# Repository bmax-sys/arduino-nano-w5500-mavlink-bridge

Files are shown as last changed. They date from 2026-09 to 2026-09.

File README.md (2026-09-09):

<p align="center">
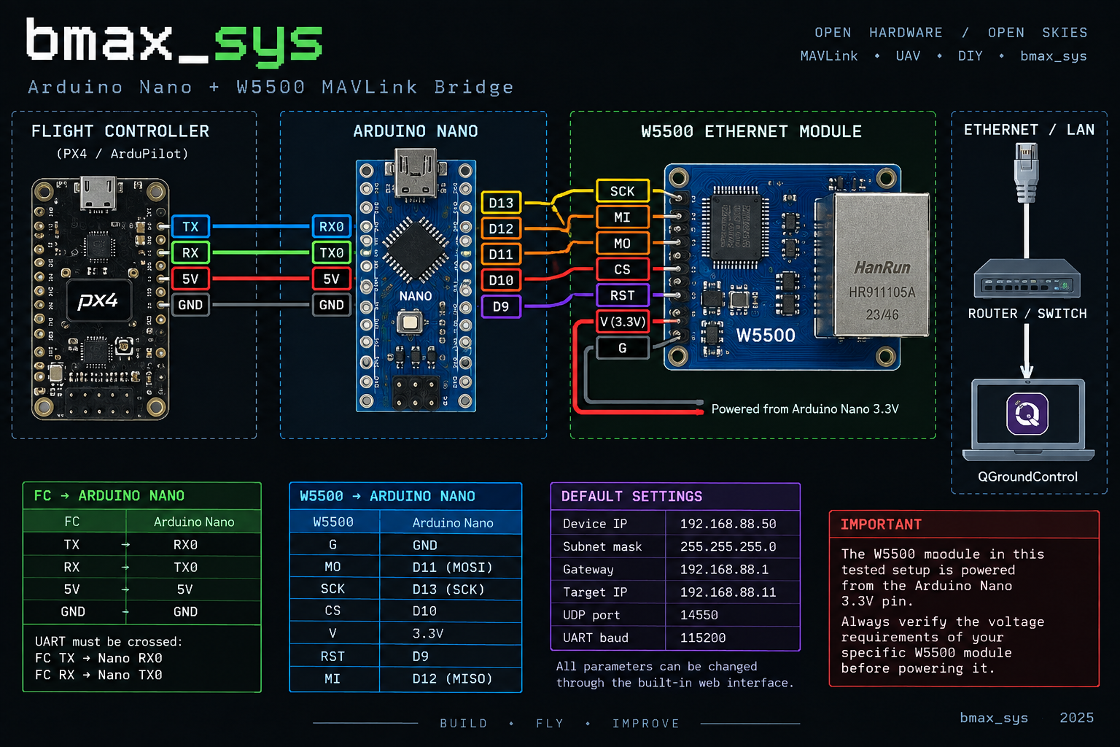
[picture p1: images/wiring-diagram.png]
bmax_sys Arduino Nano + W5500 MAVLink Bridge wiring diagram
  
</p>

# Arduino Nano + W5500 MAVLink Bridge

**UART ↔ Ethernet bridge for MAVLink telemetry based on Arduino Nano and W5500.**

Built by `bmax_sys`.

## Overview

This project turns an Arduino Nano and W5500 Ethernet module into a bidirectional UART-to-Ethernet bridge for MAVLink communication.

The flight controller sends MAVLink data through UART to the Arduino Nano. The Nano forwards the data through the W5500 Ethernet module using UDP.

Communication works in both directions:

`Flight Controller ↔ UART ↔ Arduino Nano ↔ W5500 ↔ Ethernet/UDP ↔ QGroundControl`

The device also includes a built-in web interface for changing network and UART settings without modifying or recompiling the firmware.

## Features

- Bidirectional `UART ↔ UDP` MAVLink bridge
- Arduino Nano + W5500 Ethernet
- Built-in web configuration interface
- Configurable Device IP
- Configurable Target IP
- Configurable Subnet Mask
- Configurable Gateway
- Configurable UDP port
- Configurable UART baud rate
- Settings stored in EEPROM
- Save & automatic reboot from the web interface
- Default MAVLink UDP port `14550`
- Works with QGroundControl
- Designed for wired Ethernet telemetry

  ## Hardware

The tested prototype uses:

- Arduino Nano
- W5500 Ethernet module
- ArduPilot-compatible flight controller
- Ethernet cable
- UART connection between the flight controller and Arduino Nano

  ## 3D Printable Enclosure

A 3D printable enclosure for the Arduino Nano + W5500 MAVLink Bridge is included in this repository.

STL file:

[`enclosure/ETH-NANO.STL`](enclosure/ETH-NANO.STL)

The enclosure is designed for the hardware configuration used in this project and can be printed on a standard FDM 3D printer.

Before printing, verify the dimensions and connector positions for your specific Arduino Nano and W5500 modules.

### Connections

**Flight Controller → Arduino Nano**

`TX → RX0`  
`RX → TX0`  
`5V → 5V`  
`GND → GND`

**W5500 → Arduino Nano**

`MO → D11`  
`MI → D12`  
`SCK → D13`  
`CS → D10`  
`RST → D9`  
`V → 3.3V`  
`G → GND`

For the complete wiring description, see:

[`docs/WIRING.md`](docs/WIRING.md)

## Default Configuration

The firmware starts with the following default settings:

| Parameter | Default value |
|---|---|
| Device IP | `192.168.88.50` |
| Subnet Mask | `255.255.255.0` |
| Gateway | `192.168.88.1` |
| Target IP | `192.168.88.11` |
| UDP Port | `14550` |
| UART Baud Rate | `115200` |

The settings can be changed through the built-in web interface and are stored in EEPROM.

After changing the configuration, press **SAVE & REBOOT** to store the new settings and restart the device.

## Web Interface

<p align="center">
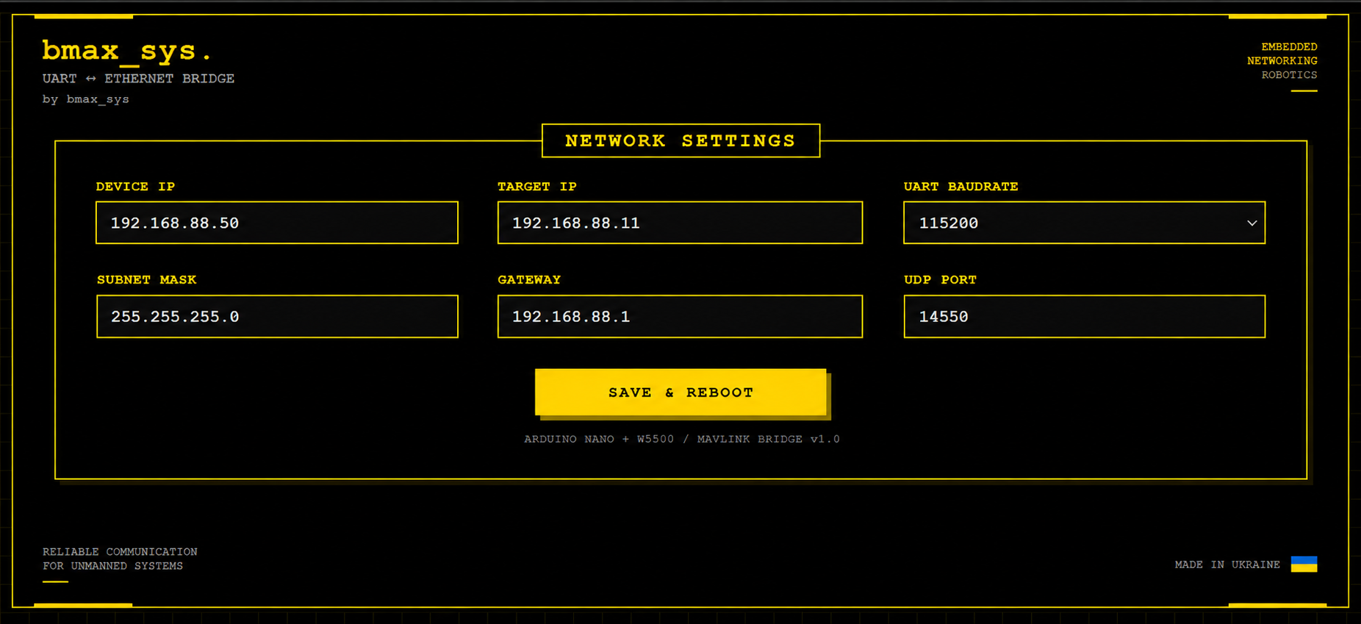
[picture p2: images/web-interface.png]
bmax_sys Arduino Nano W5500 MAVLink Bridge Web Interface
  
</p>

The bridge includes a lightweight built-in web interface hosted directly by the Arduino Nano.

Open the device IP address in a web browser:

`http://192.168.88.50`

The interface allows you to configure:

- Device IP
- Target IP
- UART baud rate
- Subnet mask
- Gateway
- UDP port

After pressing **SAVE & REBOOT**, the configuration is stored in EEPROM and the Arduino Nano automatically restarts with the new settings.

The public version of the interface uses the `bmax_sys` pixel-style branding.

## MAVLink and QGroundControl

The bridge was designed for MAVLink telemetry between an ArduPilot flight controller and QGroundControl.

Default data path:

`Flight Controller → UART → Arduino Nano → W5500 → UDP 14550 → QGroundControl`

Communication is bidirectional:

`QGroundControl → UDP → W5500 → Arduino Nano → UART → Flight Controller`

By default, MAVLink packets are sent to:

`192.168.88.11:14550`

The Target IP and UDP port can be changed from the web interface, allowing the bridge to work with different network configurations.

## Firmware

The firmware is available here:

[`firmware/arduino_nano_w5500_mavlink_bridge.ino`](firmware/arduino_nano_w5500_mavlink_bridge.ino)

Main firmware functions:

- UART → UDP forwarding
- UDP → UART forwarding
- W5500 Ethernet initialization
- Web configuration server
- EEPROM configuration storage
- IP address validation
- Configurable UART baud rate
- Automatic reboot after saving settings

The firmware is based on the Arduino Ethernet library and is designed to keep memory usage low enough for the Arduino Nano.

## Repository Structure

```text
arduino-nano-w5500-mavlink-bridge/
├── README.md
├── firmware/
│   └── arduino_nano_w5500_mavlink_bridge.ino
├── docs/
│   ├── WIRING.md
│   └── TESTING.md
├── images/
│   ├── wiring-diagram.png
│   └── web-interface.png
└── enclosure/
    └── ETH-NANO.STL
```

## Tested

The prototype has been tested with real hardware.

Confirmed:

- Arduino Nano communicates with the W5500 over SPI
- Flight controller communicates with the Nano over UART
- MAVLink telemetry is transmitted over Ethernet
- UDP communication works in both directions
- QGroundControl receives MAVLink telemetry
- Web configuration interface works
- Network settings can be changed and stored in EEPROM
- Device automatically reboots after saving settings

This repository documents a working hardware prototype, not only a theoretical design.
For detailed test results and verification steps, see:

[`docs/TESTING.md`](docs/TESTING.md)

## Important Notes

- Always connect UART lines crossed: `FC TX → Nano RX0` and `FC RX → Nano TX0`.
- Flight controller and Arduino Nano must share a common GND.
- The tested W5500 module is powered from the Arduino Nano `3.3V` pin.
- Verify the power requirements of your specific W5500 module before connecting it.
- Make sure the configured Target IP points to the computer running QGroundControl.
- UDP port `14550` is the default MAVLink port used in this project.

  ## Author

Developed and tested by `bmax_sys`.

Part of a series of embedded, networking and robotics projects focused on reliable communication for unmanned systems.

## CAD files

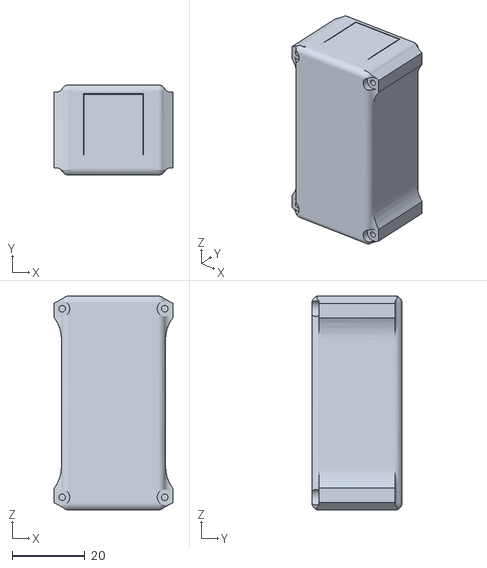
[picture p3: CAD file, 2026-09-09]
enclosure/ETH-NANO.STL
32.7 x 24.9 x 59.0

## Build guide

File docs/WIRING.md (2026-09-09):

# Wiring

This project uses an Arduino Nano and a W5500 Ethernet module as a bidirectional UART-to-Ethernet bridge for MAVLink telemetry.

## W5500 to Arduino Nano

| W5500 | Arduino Nano |
|---|---|
| G | GND |
| MO | D11 |
| SCK | D13 |
| CS | D10 |
| V | 3.3V |
| RST | D9 |
| MI | D12 |

SPI mapping:

- `D11` — MOSI
- `D12` — MISO
- `D13` — SCK
- `D10` — CS
- `D9` — W5500 Reset

## Arduino Nano to Flight Controller

| Arduino Nano | Flight Controller |
|---|---|
| RX0 | TX |
| TX0 | RX |
| 5V | 5V |
| GND | GND |

UART must be crossed:

`FC TX → Nano RX0`

`FC RX → Nano TX0`

## Data path

`Flight Controller → UART → Arduino Nano → W5500 → Ethernet → UDP → QGroundControl`

The bridge is bidirectional, so MAVLink data can travel in both directions between the flight controller and the network.

## Default network settings

- Device IP: `192.168.88.50`
- Subnet mask: `255.255.255.0`
- Gateway: `192.168.88.1`
- Target IP: `192.168.88.11`
- UDP port: `14550`
- UART baud rate: `115200`

These parameters can be changed through the built-in web interface.

## Important

The W5500 module in this tested setup is powered from the Arduino Nano `3.3V` pin.

Always verify the voltage requirements of your specific W5500 module before powering it.

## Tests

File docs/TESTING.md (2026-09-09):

# Testing

The Arduino Nano + W5500 MAVLink Bridge was tested with real hardware.

## Test Hardware

- Arduino Nano
- W5500 Ethernet module
- ArduPilot-compatible flight controller
- Ethernet network
- QGroundControl

## Test Configuration

Default bridge configuration:

| Parameter | Value |
|---|---|
| Device IP | `192.168.88.50` |
| Subnet Mask | `255.255.255.0` |
| Gateway | `192.168.88.1` |
| Target IP | `192.168.88.11` |
| UDP Port | `14550` |
| UART Baud Rate | `115200` |

## Data Path

The complete tested communication path:

`Flight Controller ↔ UART ↔ Arduino Nano ↔ SPI ↔ W5500 ↔ Ethernet/UDP ↔ QGroundControl`

## UART Test

The flight controller was connected directly to the Arduino Nano UART:

`FC TX → Nano RX0`

`FC RX → Nano TX0`

A common ground was used between the flight controller and Arduino Nano.

MAVLink data was successfully transferred through the UART connection.

## Ethernet Test

The Arduino Nano communicates with the W5500 Ethernet controller over SPI.

The W5500 successfully provides Ethernet connectivity for the bridge using the configured static IP address.

## MAVLink / UDP Test

MAVLink telemetry was forwarded from UART to Ethernet using UDP.

Default destination:

`192.168.88.11:14550`

QGroundControl successfully received MAVLink telemetry from the flight controller.

Communication was also verified in the opposite direction:

`QGroundControl → UDP → W5500 → Arduino Nano → UART → Flight Controller`

This confirms bidirectional UART ↔ UDP communication.

## Web Interface Test

The built-in configuration interface was accessed through:

`http://192.168.88.50`

The following parameters can be changed from the web interface:

- Device IP
- Target IP
- Subnet Mask
- Gateway
- UDP Port
- UART Baud Rate

The configuration is stored in EEPROM.

After pressing **SAVE & REBOOT**, the device saves the new settings and automatically restarts.

## Result

The prototype successfully provides a bidirectional MAVLink bridge between a flight controller UART and an Ethernet network.

Confirmed:

- Arduino Nano ↔ W5500 SPI communication
- Flight Controller ↔ Arduino Nano UART communication
- UART → UDP forwarding
- UDP → UART forwarding
- QGroundControl MAVLink telemetry
- Bidirectional MAVLink communication
- Built-in web configuration
- EEPROM configuration storage
- Automatic reboot after configuration changes

The project has been verified as a working hardware prototype.

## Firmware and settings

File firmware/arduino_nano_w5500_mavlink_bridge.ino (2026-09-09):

#include <SPI.h>
#include <Ethernet.h>
#include <EthernetUdp.h>
#include <EEPROM.h>
#include <avr/wdt.h>

// =====================================================
// bmax_sys
// Arduino Nano + W5500 MAVLink Bridge
// Arduino Nano + W5500
// UART <-> UDP + EEPROM + WEB SETTINGS
// =====================================================

#define W5500_CS  10
#define W5500_RST 9

byte mac[] = {0x02, 0x4D, 0x41, 0x58, 0x58, 0x06};

const byte DEF_DEVICE_IP[4] = {192,168,88,50};
const byte DEF_MASK[4]      = {255,255,255,0};
const byte DEF_GATEWAY[4]   = {192,168,88,1};
const byte DEF_TARGET_IP[4] = {192,168,88,11};

const uint16_t DEF_UDP_PORT = 14550;
const uint32_t DEF_BAUD     = 115200;

const uint32_t SETTINGS_MAGIC = 0x424D5831UL; // "BMX1"

struct Settings {
  uint32_t magic;
  byte deviceIP[4];
  byte mask[4];
  byte gateway[4];
  byte targetIP[4];
  uint16_t udpPort;
  uint32_t baud;
};

Settings cfg;

IPAddress deviceIP;
IPAddress subnetMask;
IPAddress gatewayIP;
IPAddress targetIP;

uint16_t udpPort = DEF_UDP_PORT;
uint32_t uartBaud = DEF_BAUD;

EthernetUDP udp;
EthernetServer server(80);

// Small buffers to protect Nano SRAM
byte uartBuffer[64];
byte udpBuffer[64];
byte uartLen = 0;
unsigned long lastByteTime = 0;

// =====================================================
// SETTINGS
// =====================================================

void copy4(byte *dst, const byte *src) {
  for (byte i = 0; i < 4; i++) dst[i] = src[i];
}

void setDefaults() {
  cfg.magic = SETTINGS_MAGIC;

  copy4(cfg.deviceIP, DEF_DEVICE_IP);
  copy4(cfg.mask, DEF_MASK);
  copy4(cfg.gateway, DEF_GATEWAY);
  copy4(cfg.targetIP, DEF_TARGET_IP);

  cfg.udpPort = DEF_UDP_PORT;
  cfg.baud = DEF_BAUD;
}

void applySettings() {
  deviceIP = IPAddress(
    cfg.deviceIP[0], cfg.deviceIP[1],
    cfg.deviceIP[2], cfg.deviceIP[3]
  );

  subnetMask = IPAddress(
    cfg.mask[0], cfg.mask[1],
    cfg.mask[2], cfg.mask[3]
  );

  gatewayIP = IPAddress(
    cfg.gateway[0], cfg.gateway[1],
    cfg.gateway[2], cfg.gateway[3]
  );

  targetIP = IPAddress(
    cfg.targetIP[0], cfg.targetIP[1],
    cfg.targetIP[2], cfg.targetIP[3]
  );

  udpPort = cfg.udpPort;
  uartBaud = cfg.baud;
}

void loadSettings() {
  EEPROM.get(0, cfg);

  if (cfg.magic != SETTINGS_MAGIC) {
    setDefaults();
    EEPROM.put(0, cfg);
  }

  applySettings();
}

void saveSettings() {
  cfg.magic = SETTINGS_MAGIC;
  EEPROM.put(0, cfg);
}

// =====================================================
// HELPERS
// =====================================================

bool parseIP(const char *s, byte out[4]) {
  int a, b, c, d;

  if (sscanf(s, "%d.%d.%d.%d", &a, &b, &c, &d) != 4) {
    return false;
  }

  if (a < 0 || a > 255 ||
      b < 0 || b > 255 ||
      c < 0 || c > 255 ||
      d < 0 || d > 255) {
    return false;
  }

  out[0] = (byte)a;
  out[1] = (byte)b;
  out[2] = (byte)c;
  out[3] = (byte)d;

  return true;
}

void printIP(EthernetClient &client, const byte ip[4]) {
  client.print(ip[0]); client.print('.');
  client.print(ip[1]); client.print('.');
  client.print(ip[2]); client.print('.');
  client.print(ip[3]);
}

bool getQueryValue(const char *request,
                   const char *key,
                   char *out,
                   byte outSize) {
  char token[18];
  snprintf(token, sizeof(token), "%s=", key);

  const char *p = strstr(request, token);
  if (!p) return false;

  p += strlen(token);

  byte i = 0;

  while (*p &&
         *p != '&' &&
         *p != ' ' &&
         i < outSize - 1) {
    out[i++] = *p++;
  }

  out[i] = 0;
  return true;
}

void rebootNano() {
  wdt_enable(WDTO_15MS);
  while (1) {}
}

// =====================================================
// UART -> UDP
// =====================================================

void uartToUDP() {
  while (Serial.available() && uartLen < sizeof(uartBuffer)) {
    uartBuffer[uartLen++] = Serial.read();
    lastByteTime = micros();
  }

  if (uartLen > 0 &&
      ((micros() - lastByteTime) > 2000 ||
       uartLen >= sizeof(uartBuffer))) {

    udp.beginPacket(targetIP, udpPort);
    udp.write(uartBuffer, uartLen);
    udp.endPacket();

    uartLen = 0;
  }
}

// =====================================================
// UDP -> UART
// =====================================================

void udpToUART() {
  int packetSize = udp.parsePacket();

  if (packetSize <= 0) return;

  while (packetSize > 0) {
    int chunk = packetSize;

    if (chunk > (int)sizeof(udpBuffer)) {
      chunk = sizeof(udpBuffer);
    }

    int len = udp.read(udpBuffer, chunk);

    if (len <= 0) break;

    Serial.write(udpBuffer, len);
    packetSize -= len;
  }
}

// =====================================================
// WEB
// =====================================================

void sendHttpHeader(EthernetClient &client) {
  client.println(F("HTTP/1.1 200 OK"));
  client.println(F("Content-Type: text/html; charset=UTF-8"));
  client.println(F("Cache-Control: no-store"));
  client.println(F("Connection: close"));
  client.println();
}

void sendSettingsPage(EthernetClient &client) {
  sendHttpHeader(client);

  client.println(F("<!DOCTYPE html><html><head>"));
  client.println(F("<meta charset='UTF-8'><meta name='viewport' content='width=device-width,initial-scale=1'>"));
  client.println(F("<title>bmax_sys | Nano W5500 MAVLink Bridge</title>"));

  client.println(F(
    "<style>"
    ":root{--y:#ffcc00;--g:rgba(255,204,0,.10);--f:#d0d0d0}"
    "*{box-sizing:border-box}"
    "html,body{margin:0;padding:0;width:100%;min-height:100%;background:#000;color:var(--y);font-family:'Courier New',Consolas,monospace}"
    "body{min-height:100vh;background-image:linear-gradient(var(--g) 1px,transparent 1px),linear-gradient(90deg,var(--g) 1px,transparent 1px);background-size:32px 32px}"
    ".frame{min-height:calc(100vh - 24px);margin:12px;border:2px solid var(--y);position:relative;background:#000;overflow:hidden}"
    ".frame:before,.frame:after{content:'';position:absolute;width:110px;height:6px;background:var(--y);top:-2px}"
    ".frame:before{left:24px}.frame:after{right:24px}"
    ".brand{position:absolute;top:22px;left:32px;z-index:10}.brand-main{font-family:'Lucida Console','Courier New',monospace;font-size:28px;font-weight:900;letter-spacing:3px;text-shadow:2px 0 0 #665200}"
    ".brand-sub{margin-top:4px;font-size:12px;letter-spacing:1px;color:#aaa}"
    ".top-right{position:absolute;top:26px;right:34px;font-weight:900;letter-spacing:3px;font-size:18px}"
  ));

  client.println(F(
    ".settings-wrapper{width:100%;padding:125px 50px 45px}"
    ".settings-panel{position:relative;width:100%;border:2px solid var(--y);padding:42px 42px 38px;background:#000;box-shadow:6px 6px 0 rgba(255,204,0,.08)}"
    ".panel-title{position:absolute;top:-20px;left:50%;transform:translateX(-50%);padding:5px 24px;background:#000;border:2px solid var(--y);font-weight:900;font-size:22px;letter-spacing:3px;white-space:nowrap}"
    ".settings-grid{display:grid;grid-template-columns:1fr 1fr 1fr;gap:26px 42px}"
    ".field label{display:block;margin-bottom:9px;font-size:15px;font-weight:900;letter-spacing:1px}"
    "input,select{width:100%;height:48px;padding:0 14px;color:var(--f);background:#050505;border:2px solid var(--y);outline:none;border-radius:0;font-family:'Courier New',Consolas,monospace;font-size:18px;font-weight:700}"
    ".button-wrapper{display:flex;justify-content:center;margin-top:34px}"
    ".save-button{min-width:320px;height:52px;border:2px solid var(--y);background:var(--y);color:#000;font-family:'Courier New',Consolas,monospace;font-size:17px;font-weight:900;letter-spacing:2px;cursor:pointer;box-shadow:5px 5px 0 #8f7300}"
    ".foot{text-align:center;margin-top:18px;color:#777;font-size:11px;letter-spacing:1px}"
    "@media(max-width:900px){.settings-grid{grid-template-columns:1fr}.settings-wrapper{padding:135px 20px 30px}.panel-title{font-size:17px}.save-button{min-width:100%}}"
    "</style></head><body><div class='frame'>"
  ));

  client.println(F("<div class='brand'><div class='brand-main'>bmax_sys</div><div class='brand-sub'>UART / ETHERNET MAVLink BRIDGE</div></div>"));
  client.println(F("<div class='top-right'>bmax_sys</div>"));
  client.println(F("<div class='settings-wrapper'><form method='GET' action='/save'><div class='settings-panel'>"));
  client.println(F("<div class='panel-title'>NETWORK SETTINGS</div><div class='settings-grid'>"));

  client.print(F("<div class='field'><label>DEVICE IP</label><input name='deviceIP' value='"));
  printIP(client, cfg.deviceIP);
  client.println(F("' required></div>"));

  client.print(F("<div class='field'><label>TARGET IP</label><input name='targetIP' value='"));
  printIP(client, cfg.targetIP);
  client.println(F("' required></div>"));

  client.println(F("<div class='field'><label>UART BAUDRATE</label><select name='baud'>"));
  const uint32_t rates[] = {9600UL,19200UL,38400UL,57600UL,115200UL,230400UL};
  for (byte i=0;i<6;i++) {
    client.print(F("<option value='")); client.print(rates[i]); client.print('\'');
    if (cfg.baud == rates[i]) client.print(F(" selected"));
    client.print('>'); client.print(rates[i]); client.println(F("</option>"));
  }
  client.println(F("</select></div>"));

  client.print(F("<div class='field'><label>SUBNET MASK</label><input name='mask' value='"));
  printIP(client, cfg.mask);
  client.println(F("' required></div>"));

  client.print(F("<div class='field'><label>GATEWAY</label><input name='gateway' value='"));
  printIP(client, cfg.gateway);
  client.println(F("' required></div>"));

  client.print(F("<div class='field'><label>UDP PORT</label><input type='number' name='port' value='"));
  client.print(cfg.udpPort);
  client.println(F("' required></div>"));

  client.println(F(
    "</div><div class='button-wrapper'><button type='submit' class='save-button'>SAVE & REBOOT</button></div>"
    "<div class='foot'>ARDUINO NANO + W5500 / bmax_sys v1.0</div>"
    "</div></form></div></div></body></html>"
  ));
}
void sendSavedPage(EthernetClient &client) {
  sendHttpHeader(client);
  client.println(F(
    "<!DOCTYPE html><html><head><meta charset='UTF-8'><meta name='viewport' content='width=device-width,initial-scale=1'>"
    "<title>Settings Saved</title><style>"
    "body{margin:0;background:#000;color:#ffcc00;font-family:'Courier New',Consolas,monospace}"
    ".frame{min-height:calc(100vh - 24px);margin:12px;border:2px solid #ffcc00;display:flex;align-items:center;justify-content:center;text-align:center}"
    ".box{padding:34px;border:2px solid #ffcc00;box-shadow:6px 6px 0 rgba(255,204,0,.10)}"
    ".check{width:70px;height:70px;margin:0 auto 22px;border:3px solid #ffcc00;display:flex;align-items:center;justify-content:center;font-size:38px;font-weight:900}"
    "h1{margin:0 0 10px;font-size:28px;letter-spacing:2px}.line{height:2px;background:#ffcc00;margin:24px 0}.ip{font-size:18px;font-weight:900}"
    "</style></head><body><div class='frame'><div class='box'>"
    "<div class='check'>&#10003;</div><h1>SETTINGS SAVED</h1><div>Device is rebooting...</div>"
    "<div class='line'></div><div>Reconnect to:</div><div class='ip'>http://"
  ));
  printIP(client, cfg.deviceIP);
  client.println(F("</div></div></div></body></html>"));
}
void sendError(EthernetClient &client, const __FlashStringHelper *msg) {
  client.println(F("HTTP/1.1 400 Bad Request"));
  client.println(F("Content-Type: text/plain"));
  client.println(F("Connection: close"));
  client.println();
  client.println(msg);
}

void handleSave(EthernetClient &client, const char *request) {
  char value[24];
  byte tempIP[4];

  if (!getQueryValue(request, "deviceIP", value, sizeof(value)) ||
      !parseIP(value, tempIP)) {
    sendError(client, F("Invalid Device IP"));
    return;
  }
  copy4(cfg.deviceIP, tempIP);

  if (!getQueryValue(request, "targetIP", value, sizeof(value)) ||
      !parseIP(value, tempIP)) {
    sendError(client, F("Invalid Target IP"));
    return;
  }
  copy4(cfg.targetIP, tempIP);

  if (!getQueryValue(request, "mask", value, sizeof(value)) ||
      !parseIP(value, tempIP)) {
    sendError(client, F("Invalid Subnet Mask"));
    return;
  }
  copy4(cfg.mask, tempIP);

  if (!getQueryValue(request, "gateway", value, sizeof(value)) ||
      !parseIP(value, tempIP)) {
    sendError(client, F("Invalid Gateway"));
    return;
  }
  copy4(cfg.gateway, tempIP);

  if (!getQueryValue(request, "port", value, sizeof(value))) {
    sendError(client, F("Missing UDP Port"));
    return;
  }

  long newPort = atol(value);

  if (newPort < 1 || newPort > 65535) {
    sendError(client, F("Invalid UDP Port"));
    return;
  }

  cfg.udpPort = (uint16_t)newPort;

  if (!getQueryValue(request, "baud", value, sizeof(value))) {
    sendError(client, F("Missing Baud"));
    return;
  }

  long newBaud = atol(value);

  if (newBaud < 1200 || newBaud > 230400) {
    sendError(client, F("Invalid Baud"));
    return;
  }

  cfg.baud = (uint32_t)newBaud;

  saveSettings();
  sendSavedPage(client);

  delay(150);
  client.stop();
  delay(500);

  rebootNano();
}

void handleWeb() {
  EthernetClient client = server.available();

  if (!client) return;

  char requestLine[220];
  byte pos = 0;

  unsigned long timeout = millis();

  // Read only first HTTP line.
  // This is enough because the web UI uses GET for saving.
  while (client.connected() &&
         millis() - timeout < 1000 &&
         pos < sizeof(requestLine) - 1) {

    if (client.available()) {
      char c = client.read();

      if (c == '\n') {
        break;
      }

      if (c != '\r') {
        requestLine[pos++] = c;
      }
    }
  }

  requestLine[pos] = 0;

  // Drain remaining headers quickly
  bool blankLine = false;
  byte lineLen = 0;
  timeout = millis();

  while (client.connected() &&
         millis() - timeout < 500 &&
         !blankLine) {

    if (client.available()) {
      char c = client.read();

      if (c == '\n') {
        if (lineLen == 0) {
          blankLine = true;
        }
        lineLen = 0;
      }
      else if (c != '\r') {
        lineLen++;
      }
    }
  }

  if (strncmp(requestLine, "GET /save?", 10) == 0) {
    handleSave(client, requestLine);
    return;
  }

  sendSettingsPage(client);

  delay(2);
  client.stop();
}

// =====================================================
// SETUP
// =====================================================

void setup() {
  loadSettings();

  Serial.begin(uartBaud);

  pinMode(W5500_RST, OUTPUT);

  digitalWrite(W5500_RST, LOW);
  delay(200);

  digitalWrite(W5500_RST, HIGH);
  delay(1000);

  Ethernet.init(W5500_CS);

  Ethernet.begin(
    mac,
    deviceIP,
    gatewayIP,  // DNS
    gatewayIP,  // Gateway
    subnetMask
  );

  delay(1000);

  udp.begin(udpPort);
  server.begin();
}

// =====================================================
// LOOP
// =====================================================

void loop() {
  uartToUDP();
  udpToUART();
  handleWeb();
}

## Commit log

2026-09-09 Add Arduino Nano W5500 MAVLink bridge firmware
2026-09-09 Add hardware wiring documentation
2026-09-09 Move wiring diagram to images folder
2026-09-09 Add 3D printable enclosure
    [ETH-NANO.STL]
2026-09-09 Move STL to enclosure folder
    [ETH-NANO.STL]
2026-09-09 Add 3D printable enclosure documentation
